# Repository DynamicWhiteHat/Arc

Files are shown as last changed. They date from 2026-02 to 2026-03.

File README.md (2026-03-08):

# Arc
A Wireless 75% Backlit Keyboard

> [!NOTE]
> Firmware available [here](https://github.com/DynamicWhiteHat/ArcFirmware)

## Features:
- HolyIOT 18010 MCU
- RGB backlight and underglow
- Nice!View e-paper display
- Wireless ZMK firmware

## Image Gallery:
<table align="center">
  <tr>
    <td align="center">
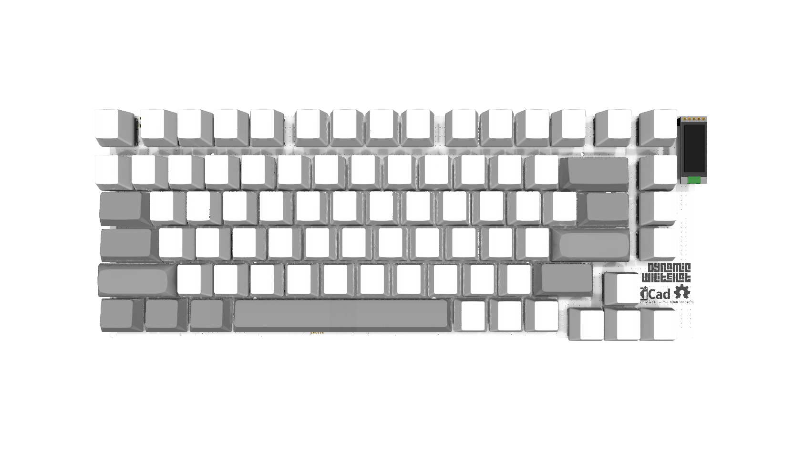
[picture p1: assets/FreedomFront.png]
      
    </td>
    <td align="center">
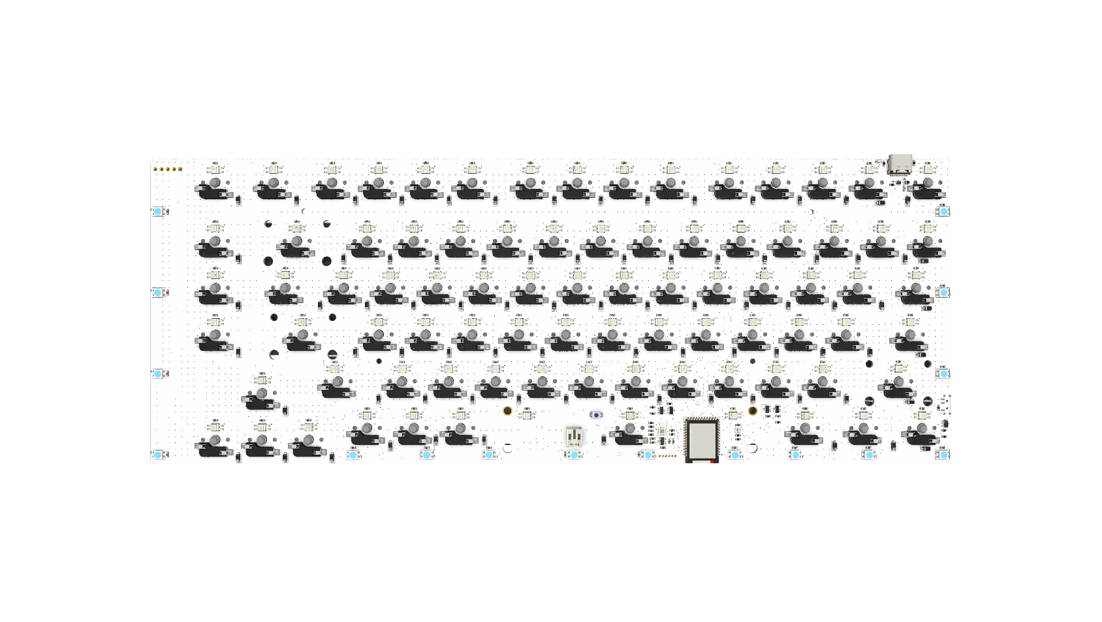
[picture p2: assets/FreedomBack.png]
      
    </td>
  </tr>
  <tr>
    <td align="center" colspan="2">
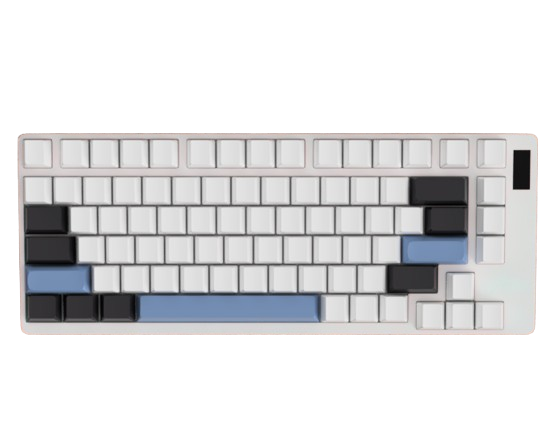
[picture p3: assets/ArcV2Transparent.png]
      
    </td>
  </tr>
</table>

## Why I Designed This Project:

After designing Corneucopia, I decided that I wanted to create a regular keyboard. I have attempted to make many in the past, but
I never got around to finishing them. Now that I had experience making a wireless split, I decided to make a wireless regular. This was also a test of making a PCB with just the MCU. Previously, I have made PCBs with the ESP32 SoM, but this was my first chip PCB that didn't use the ESP32.

## Schematics And PCBS:
<table align="center">
  <tr>
    <td align="center" colspan="2">
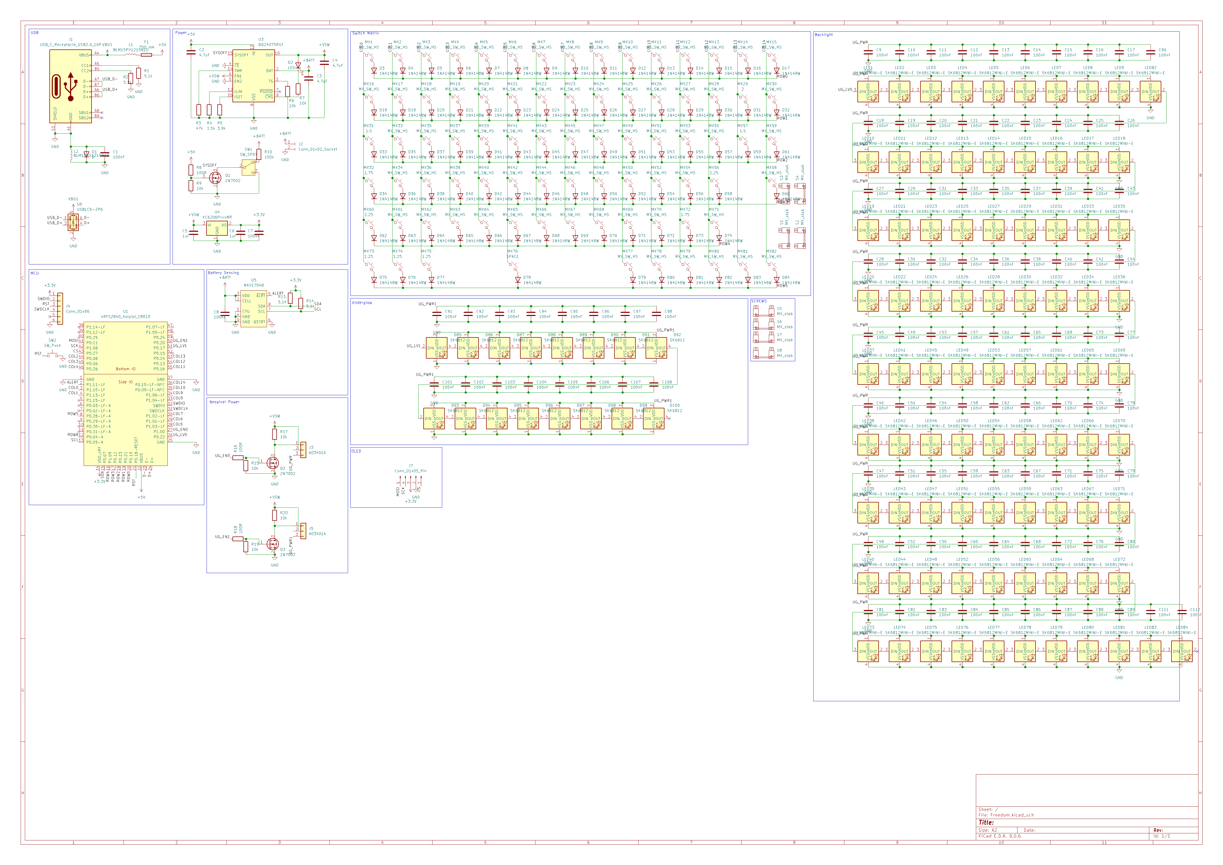
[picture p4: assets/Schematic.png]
      
    </td>
  </tr>
  <tr>
     <td align="center">
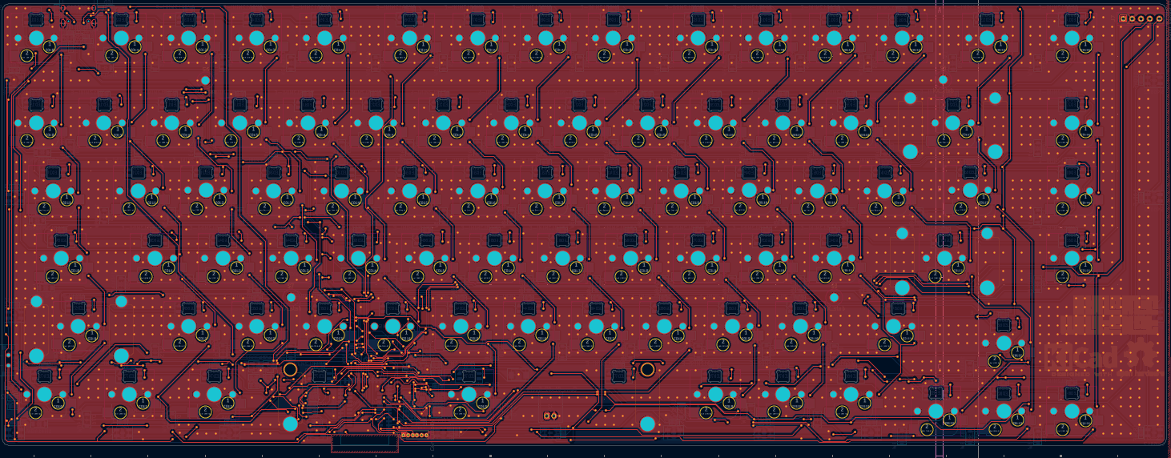
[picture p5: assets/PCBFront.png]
      
    </td>
    <td align="center">
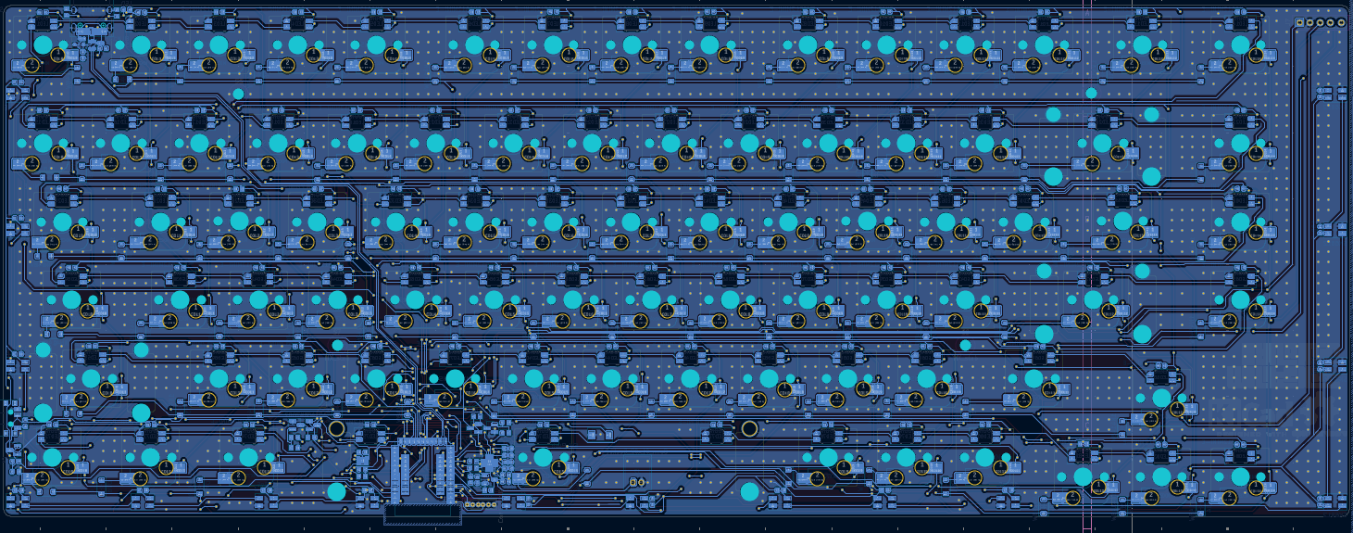
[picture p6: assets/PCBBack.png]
      
    </td>
  </tr>
</table>

## Usage:
The project features a design that keeps all screws hidden on the inside of the case, keeping a seamless look on the outside. This design has already been applied in [Corneucopia](https://github.com/DynamicWhiteHat/Corneucopia/). The PCB is screwed into the bottom case using 4 M2 screws. The top case is held in place by the hot-swappable switches. Once the PCB is assembled and the case is build, load the AdaFruit nrf52840 bootloader onto it, available [here](https://github.com/adafruit/Adafruit_nRF52_Bootloader). Follow [this guide](https://github.com/joric/nrfmicro/wiki/Bootloader) for more help. After adding the bootloader, enter dfu mode using the reset button and upload the .uf2 file from the firmware folder on this repository. The keyboard is now ready.

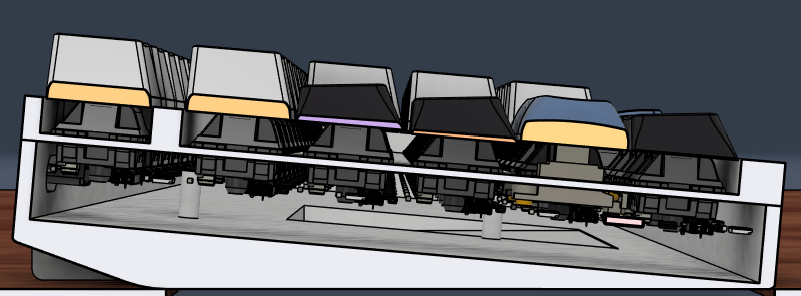
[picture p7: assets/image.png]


## Details:
Powered by a HolyIOT 18010, running ZMK firmware, this board supports a wireless Bluetooth connection. It uses the SK6812 mini-e for per-key RGB, and regular the sk6812 mini for underglow. A laser-cut stencil will be used to help with PCB assembly.

## BOM:
| Part | Quantity | Price | Link | | | | |
|---|---|---|---|---|---|---|---|
| PCB + Stencil | 1 Order | $40.56 | JLCPCB Quote | | | | |
| PCB Parts | 1 Order | $32.22 | See LCSC BOM | | | | |
| Switches | 2 Packs of 50 | $19.82 | https://www.aliexpress.us/item/3256806837508228.html | | | | |
| Hotswaps | 1 Pack Of 100 | $9.45 | https://www.aliexpress.us/item/2251832764937566.html | | | | |
| Stabilizers | 1 Pack | $17.99 | https://www.amazon.com/DUROCK-Stabilizers-Translucent-Keyboard-Mechanical/dp/B0B2RR8YB3/ | | | | |
| HolyIOT 18010 MCU | 1 | $12.84 | https://www.aliexpress.us/item/3256804605353119.html | | | | |
| Keycaps | 1 | $23.92 | https://www.aliexpress.com/i/3256807057714410.html | | | | |
| Lipo Battery | 1 | $10.49 | https://www.amazon.com/Qimoo-Battery-Rechargeable-Connector-Electronic/dp/B0CNLNKSKK/ | | | | |
| | | $167.29 | | | | | |
| LCSC | | | | | | | |
| Description | Quantity Needed | Mrf# | Minimum Order Qty. | Unit Price(USD) | Ext.Price(USD) | LCSC# | Product Link |
| 1.5k | 1 | 0603WAF1501T5E | 100 | 0.0012 | 0.12 | C22843 | https://www.lcsc.com/product-detail/C22843.html |
| 100R | 3 | 0603WAF1000T5E | 100 | 0.0012 | 0.12 | C22775 | https://www.lcsc.com/product-detail/C22775.html |
| 100k | 1 | 0603WAF1003T5E | 100 | 0.0011 | 0.11 | C25803 | https://www.lcsc.com/product-detail/C25803.html |
| 100nF | 103 | CC0603KRX7R9BB104  | 200 | 0.0021 | 0.42 | C14663 | https://www.lcsc.com/product-detail/C14663.html |
| 10k | 7 | 0603WAF1002T5E | 100 | 0.0012 | 0.12 | C25804 | https://www.lcsc.com/product-detail/C25804.html |
| 1N4148W | 82 | 1N4148W | 100 | 0.011 | 1.1 | C81598 | https://www.lcsc.com/product-detail/C81598.html |
| 1uF | 2 | CL10A105KB8NNNC | 50 | 0.0056 | 0.28 | C15849 | https://www.lcsc.com/product-detail/C15849.html |
| 2N7002 | 3 | 2N7002 | 50 | 0.0137 | 0.69 | C8545 | https://www.lcsc.com/product-detail/C8545.html |
| 3.9k | 1 | 0603WAF3901T5E | 100 | 0.0014 | 0.14 | C23018 | https://www.lcsc.com/product-detail/C23018.html |
| 4.7uF | 3 | CL10A475KO8NNNC | 10 | 0.0103 | 0.1 | C19666 | https://www.lcsc.com/product-detail/C19666.html |
| 47k | 1 | 0603WAF4702T5E | 100 | 0.0012 | 0.12 | C25819 | https://www.lcsc.com/product-detail/C25819.html |
| 5.1K | 1 | 0603WAF5101T5E | 100 | 0.0012 | 0.12 | C23186 | https://www.lcsc.com/product-detail/C23186.html |
| 5.1k | 3 | 0603WAF5101T5E | 100 | 0.0012 | 0.12 | C23186 | https://www.lcsc.com/product-detail/C23186.html |
| 750 mA | 1 | BSMD0603-075-6V | 10 | 0.0656 | 0.66 | C914092  | https://www.lcsc.com/product-detail/C914092.html  |
| A03401A | 2 | AO3401A | 10 | 0.0583 | 0.58 | C15127 | https://www.lcsc.com/product-detail/C15127.html |
| BLM15PX121SN1D | 2 | BLM15PX121SN1D | 100 | 0.0059 | 0.59 | C88970 | https://www.lcsc.com/product-detail/C88970.html |
| BQ24075RGT | 1 | BQ24075RGTT | 1 | 1.4633 | 1.46 | C2865459 | https://www.lcsc.com/product-detail/C2865459.html |
| Conn_01x02_Socket | 1 | S2B-PH-K-S(LF)(SN) | 20 | 0.0372 | 0.74 | C173752  | https://www.lcsc.com/product-detail/C173752.html  |
| D | 1 | BSD3C051V | 10 | 0.069 | 0.69 | C151996  | https://www.lcsc.com/product-detail/C151996.html  |
| LED | 1 | KT-0603W | 50 | 0.0118 | 0.59 | C2290 | https://www.lcsc.com/product-detail/C2290.html |
| MAX17048 | 1 | MAX17048G+T10 | 1 | 2.6708 | 2.67 | C2682616 | https://www.lcsc.com/product-detail/C2682616.html |
| SK6812 | 16 | SK6812SMINI | 20 | 0.0618 | 1.24 | C7423118 | https://www.lcsc.com/product-detail/C7423118.html |
| SK6812MINI-E | 84 | SK6812MINI-E | 85 | 0.0742 | 6.31 | C5149201 | https://www.lcsc.com/product-detail/C5149201.html |
| SW_Push | 1 | TS-1088-AR02016 | 10 | 0.0455 | 0.46 | C720477  | https://www.lcsc.com/product-detail/C720477.html  |
| SW_SPDT | 1 | SSSS811101 | 5 | 0.1439 | 0.72 | C109335  | https://www.lcsc.com/product-detail/C109335.html  |
| USBLC6-2P6 | 1 | USBLC6-2P6-MS | 5 | 0.1024 | 0.51 | C3647099 | https://www.lcsc.com/product-detail/C3647099.html |
| USB_C_Receptacle_USB2.0_16P | 1 | TYPE-C-31-M-12 | 5 | 0.1681 | 0.84 | C165948  | https://www.lcsc.com/product-detail/C165948.html  |
| XC6206PxxxMR | 1 | XC6206P332MR-G | 5 | 0.11 | 0.55 | C5446 | https://www.lcsc.com/product-detail/C5446.html |
| | | | | Subtotal: | $22.35 | | |
| | | | | Shipping: | $9.87 | | |
| | | | | Total: | $32.22 | | |

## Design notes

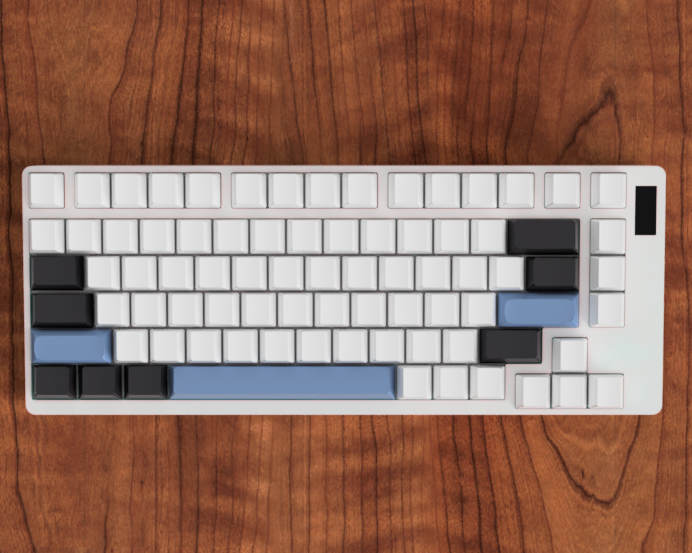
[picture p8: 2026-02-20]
assets/ArcV2.png

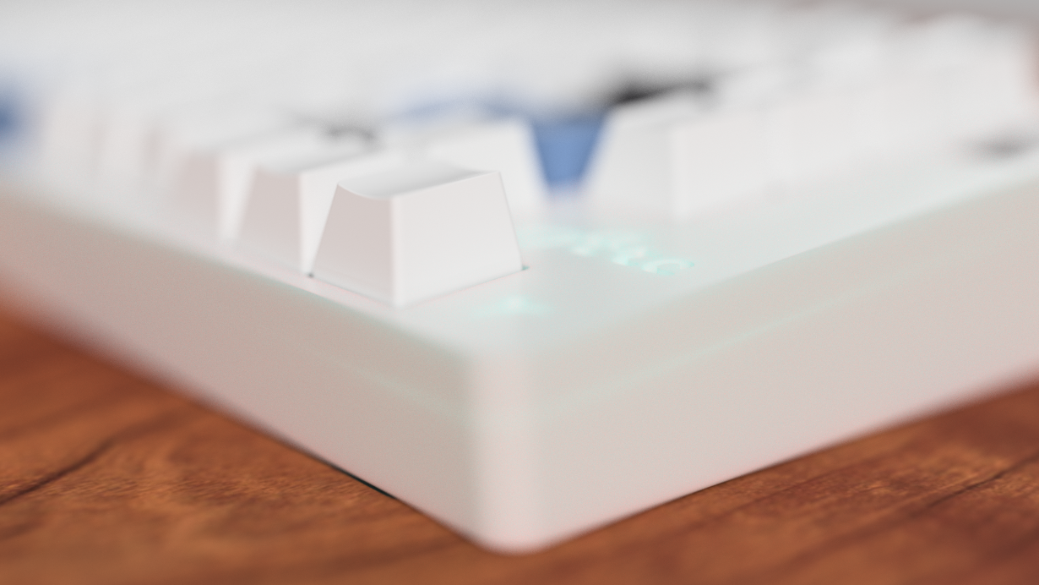
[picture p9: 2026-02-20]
assets/ArcV2Blur.png

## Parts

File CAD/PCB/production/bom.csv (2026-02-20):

Designator | Footprint | Quantity | Value | LCSC Part #
C1, C10, C101, C102, C103, C104, C105, C106, C107, C108, C11, C111, C112, C12, C13, C14, C15, C16, C17, C18, C19, C20, C21, C22, C23, C24, C25, C26, C27, C28, C29, C30, C31, C32, C33, C34, C35, C36, C37, C38, C39, C40, C41, C42, C43, C44, C45, C46, C47, C48, C49, C50, C51, C52, C53, C54, C55, C56, C57, C58, C59, C60, C61, C62, C63, C64, C65, C66, C67, C68, C69, C7, C70, C71, C72, C73, C74, C75, C76, C77, C78, C79, C8, C80, C81, C82, C83, C84, C85, C86, C87, C88, C89, C9, C90, C91, C92, C93, C94, C95, C96, C97, C98 | 0603 | 103 | 100nF
C2, C3, C4 | 0603 | 3 | 4.7uF
C5, C6 | 0603 | 2 | 1uF
D1 | D_SOD-323 | 1 | D
D10, D11, D12, D13, D14, D15, D16, D17, D18, D19, D20, D21, D22, D23, D24, D25, D26, D27, D28, D29, D3, D30, D31, D32, D33, D34, D35, D36, D37, D38, D39, D4, D40, D41, D42, D43, D44, D45, D46, D47, D48, D49, D5, D50, D51, D52, D53, D54, D55, D56, D57, D58, D59, D6, D60, D61, D62, D63, D64, D65, D66, D67, D68, D69, D7, D70, D71, D72, D73, D74, D75, D76, D77, D78, D79, D8, D80, D81, D82, D83, D84, D9 | D_SOD-123 | 82 | 1N4148W
D100, D85, D86, D87, D88, D89, D90, D91, D92, D93, D94, D95, D96, D97, D98, D99 | LED_SK6812MINI_PLCC4_3.5x3.5mm_P1.75mm | 16 | SK6812
D2 | 0603 | 1 | LED
F1 | 0603 | 1 | 750 mA
J1 | USB_C_Receptacle_HRO_TYPE-C-31-M-12 | 1 | USB_C_Receptacle_USB2.0_16P
J2 | JST_PH_S2B-PH-K_1x02_P2.00mm_Horizontal | 1 | Conn_01x02_Socket
J3, J5 | SOT-23 | 2 | A03401A
J4 | PinHeader_1x06_P1.27mm_Vertical | 1 | Conn_01x06
J7 | PinHeader_1x05_P2.54mm_Vertical | 1 | Conn_01x05_Pin
L1, L2 | 0402 | 2 | BLM15PX121SN1D
LED1, LED10, LED11, LED12, LED13, LED14, LED15, LED16, LED17, LED18, LED19, LED2, LED20, LED21, LED22, LED23, LED24, LED25, LED26, LED27, LED28, LED29, LED3, LED30, LED31, LED32, LED33, LED34, LED35, LED36, LED37, LED38, LED39, LED4, LED40, LED41, LED42, LED43, LED44, LED45, LED46, LED47, LED48, LED49, LED5, LED50, LED51, LED52, LED53, LED54, LED55, LED56, LED57, LED58, LED59, LED6, LED60, LED61, LED62, LED63, LED64, LED65, LED66, LED67, LED68, LED69, LED7, LED70, LED71, LED72, LED73, LED74, LED75, LED76, LED77, LED78, LED79, LED8, LED80, LED81, LED82, LED83, LED84, LED9 | LED_MX_6028R | 84 | SK6812MINI-E
MX1, MX10, MX11, MX12, MX13, MX14, MX15, MX16, MX17, MX18, MX19, MX2, MX20, MX21, MX22, MX23, MX24, MX25, MX26, MX27, MX28, MX3, MX30, MX33, MX34, MX35, MX36, MX37, MX38, MX39, MX4, MX40, MX41, MX42, MX43, MX44, MX45, MX46, MX47, MX48, MX49, MX5, MX50, MX51, MX52, MX53, MX54, MX55, MX58, MX59, MX6, MX61, MX62, MX63, MX64, MX65, MX66, MX67, MX68, MX69, MX7, MX70, MX71, MX77, MX78, MX79, MX8, MX80, MX81, MX82, MX9 | SW_MX_HS_CPG151101S11_1u | 71 | MX_SW_HS
MX29 | SW_MX_HS_CPG151101S11_2u | 1 | 2
MX31, MX57 | SW_MX_HS_CPG151101S11_1.5u | 2 | 1.5
MX32, MX72 | SW_MX_HS_CPG151101S11_1.75u | 2 | 1.75
MX56, MX60 | SW_MX_HS_CPG151101S11_2.25u | 2 | 2.25
MX73, MX74, MX75 | SW_MX_HS_CPG151101S11_1.25u | 3 | 1.25
MX76 | SW_MX_HS_CPG151101S11_6u | 1 | SPACE
Q1, Q2, Q3 | SOT-23 | 3 | 2N7002
R1, R13, R14, R2 | 0603 | 4 | 5.1k
R10 | 0603 | 1 | 100k
R15, R17, R19, R20, R6, R7, R9 | 0603 | 7 | 10k
R16, R18, R8 | 0603 | 3 | 100R
R3 | 0603 | 1 | 47k
R4 | 0603 | 1 | 1.5k
R5 | 0603 | 1 | 3.9k
S1 | STAB_MX_P_6.25u | 1 | MX_stab
S2, S4 | STAB_MX_2.25u | 2 | MX_stab
S3 | STAB_MX_2u | 1 | MX_stab
S5, S6, S7, S8 | MountingHole_2.2mm_M2 | 4 | MX_stab
SW1 | SW_SSSS811101 | 1 | SW_SPDT
SW2 | SW_TS-1088-AR02016 | 1 | SW_Push
U1 | nRF52840_holyiot_18010 | 1 | nRF52840_holyiot_18010
U3 | VQFN-16-1EP_3x3mm_P0.5mm_EP1.6x1.6mm | 1 | BQ24075RGT
U4 | SOT-23-3 | 1 | XC6206PxxxMR
U5 | DFN-8-1EP_2x2mm_P0.5mm_EP0.8x1.6mm | 1 | MAX17048
U6 | SOT-666 | 1 | USBLC6-2P6

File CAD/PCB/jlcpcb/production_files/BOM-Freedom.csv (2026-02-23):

Comment | Designator | Footprint | LCSC | Quantity
1.5k | R4 | R_0603_1608Metric | C22843 | 1
100R | R16,R18,R8 | R_0603_1608Metric | C22775 | 3
100k | R10 | R_0603_1608Metric | C25803 | 1
100nF | C1,C10,C101,C102,C103,C104,C105,C106,C107,C108,C11,C111,C112,C12,C13,C14,C15,C16,C17,C18,C19,C20,C21,C22,C23,C24,C25,C26,C27,C28,C29,C30,C31,C32,C33,C34,C35,C36,C37,C38,C39,C40,C41,C42,C43,C44,C45,C46,C47,C48,C49,C50,C51,C52,C53,C54,C55,C56,C57,C58,C59,C60,C61,C62,C63,C64,C65,C66,C67,C68,C69,C7,C70,C71,C72,C73,C74,C75,C76,C77,C78,C79,C8,C80,C81,C82,C83,C84,C85,C86,C87,C88,C89,C9,C90,C91,C92,C93,C94,C95,C96,C97,C98 | C_0603_1608Metric | C14663 | 103
10k | R15,R17,R19,R20,R6,R7,R9 | R_0603_1608Metric | C25804 | 7
1N4148W | D10,D11,D12,D13,D14,D15,D16,D17,D18,D19,D20,D21,D22,D23,D24,D25,D26,D27,D28,D29,D3,D30,D31,D32,D33,D34,D35,D36,D37,D38,D39,D4,D40,D41,D42,D43,D44,D45,D46,D47,D48,D49,D5,D50,D51,D52,D53,D54,D55,D56,D57,D58,D59,D6,D60,D61,D62,D63,D64,D65,D66,D67,D68,D69,D7,D70,D71,D72,D73,D74,D75,D76,D77,D78,D79,D8,D80,D81,D82,D83,D84,D9 | D_SOD-123 | C81598 | 82
1uF | C5,C6 | C_0603_1608Metric | C15849 | 2
2N7002 | Q1,Q2,Q3 | SOT-23 | C8545 | 3
3.9k | R5 | R_0603_1608Metric | C23018 | 1
4.7uF | C2,C3,C4 | C_0603_1608Metric | C19666 | 3
47k | R3 | R_0603_1608Metric | C25819 | 1
5.1K | R13 | R_0603_1608Metric | C23186 | 1
5.1k | R1,R14,R2 | R_0603_1608Metric | C23186 | 3
750 mA | F1 | Fuse_0603_1608Metric | C914092 | 1
A03401A | J3,J5 | SOT-23 | C9900019683 | 2
BLM15PX121SN1D | L1,L2 | C_0402_1005Metric | C88970 | 2
BQ24075RGT | U3 | VQFN-16-1EP_3x3mm_P0.5mm_EP1.6x1.6mm | C2865459 | 1
Conn_01x02_Socket | J2 | JST_PH_S2B-PH-K_1x02_P2.00mm_Horizontal | C173752 | 1
D | D1 | D_SOD-323 | C151996 | 1
LED | D2 | LED_0603_1608Metric | C2290 | 1
MAX17048 | U5 | DFN-8-1EP_2x2mm_P0.5mm_EP0.8x1.6mm | C2682616 | 1
SK6812 | D100,D85,D86,D87,D88,D89,D90,D91,D92,D93,D94,D95,D96,D97,D98,D99 | LED_SK6812MINI_PLCC4_3.5x3.5mm_P1.75mm | C7423118 | 16
SK6812MINI-E | LED1,LED10,LED11,LED12,LED13,LED14,LED15,LED16,LED17,LED18,LED19,LED2,LED20,LED21,LED22,LED23,LED24,LED25,LED26,LED27,LED28,LED29,LED3,LED30,LED31,LED32,LED33,LED34,LED35,LED36,LED37,LED38,LED39,LED4,LED40,LED41,LED42,LED43,LED44,LED45,LED46,LED47,LED48,LED49,LED5,LED50,LED51,LED52,LED53,LED54,LED55,LED56,LED57,LED58,LED59,LED6,LED60,LED61,LED62,LED63,LED64,LED65,LED66,LED67,LED68,LED69,LED7,LED70,LED71,LED72,LED73,LED74,LED75,LED76,LED77,LED78,LED79,LED8,LED80,LED81,LED82,LED83,LED84,LED9 | LED_MX_6028R | C5149201 | 84
SW_Push | SW2 | SW_TS-1088-AR02016 | C720477 | 1
SW_SPDT | SW1 | SW_SSSS811101 | C109335 | 1
USBLC6-2P6 | U6 | SOT-666 | C3647099 | 1
USB_C_Receptacle_USB2.0_16P | J1 | USB_C_Receptacle_HRO_TYPE-C-31-M-12 | C165948 | 1
XC6206PxxxMR | U4 | SOT-23-3 | C5446 | 1
MX_stab | S6 | MountingHole_2.2mm_M2 |  | 1
Conn_01x06 | J4 | PinHeader_1x06_P1.27mm_Vertical |  | 1
MX_stab | S7 | MountingHole_2.2mm_M2 |  | 1
MX_stab | S1 | STAB_MX_P_6.25u |  | 1
Conn_01x05_Pin | J7 | PinSocket_1x05_P2.54mm_Vertical |  | 1
MX_stab | S8 | MountingHole_2.2mm_M2 |  | 1
MX_stab | S4 | STAB_MX_2.25u |  | 1
MX_stab | S3 | STAB_MX_2u |  | 1
MX_stab | S5 | MountingHole_2.2mm_M2 |  | 1
MX_stab | S2 | STAB_MX_2.25u |  | 1
MX_SW_HS | MX37 | SW_MX_HS_CPG151101S11_1u |  | 1
1.75 | MX32 | SW_MX_HS_CPG151101S11_1.75u |  | 1
1.75 | MX72 | SW_MX_HS_CPG151101S11_1.75u |  | 1
MX_SW_HS | MX80 | SW_MX_HS_CPG151101S11_1u |  | 1
MX_SW_HS | MX33 | SW_MX_HS_CPG151101S11_1u |  | 1
MX_SW_HS | MX79 | SW_MX_HS_CPG151101S11_1u |  | 1
nRF52840_holyiot_18010 | U1 | nRF52840_holyiot_18010 |  | 1
1.25 | MX75 | SW_MX_HS_CPG151101S11_1.25u |  | 1
SPACE | MX76 | SW_MX_HS_CPG151101S11_6u |  | 1
2 | MX29 | SW_MX_HS_CPG151101S11_2u |  | 1
MX_SW_HS | MX2 | SW_MX_HS_CPG151101S11_1u |  | 1
1.5 | MX31 | SW_MX_HS_CPG151101S11_1.5u |  | 1
MX_SW_HS | MX64 | SW_MX_HS_CPG151101S11_1u |  | 1
MX_SW_HS | MX42 | SW_MX_HS_CPG151101S11_1u |  | 1
MX_SW_HS | MX66 | SW_MX_HS_CPG151101S11_1u |  | 1
1.5 | MX57 | SW_MX_HS_CPG151101S11_1.5u |  | 1
MX_SW_HS | MX22 | SW_MX_HS_CPG151101S11_1u |  | 1
MX_SW_HS | MX17 | SW_MX_HS_CPG151101S11_1u |  | 1
MX_SW_HS | MX53 | SW_MX_HS_CPG151101S11_1u |  | 1
MX_SW_HS | MX52 | SW_MX_HS_CPG151101S11_1u |  | 1
MX_SW_HS | MX41 | SW_MX_HS_CPG151101S11_1u |  | 1
MX_SW_HS | MX21 | SW_MX_HS_CPG151101S11_1u |  | 1
MX_SW_HS | MX54 | SW_MX_HS_CPG151101S11_1u |  | 1
MX_SW_HS | MX51 | SW_MX_HS_CPG151101S11_1u |  | 1
MX_SW_HS | MX62 | SW_MX_HS_CPG151101S11_1u |  | 1
MX_SW_HS | MX59 | SW_MX_HS_CPG151101S11_1u |  | 1
MX_SW_HS | MX55 | SW_MX_HS_CPG151101S11_1u |  | 1
MX_SW_HS | MX46 | SW_MX_HS_CPG151101S11_1u |  | 1
MX_SW_HS | MX45 | SW_MX_HS_CPG151101S11_1u |  | 1
MX_SW_HS | MX43 | SW_MX_HS_CPG151101S11_1u |  | 1
MX_SW_HS | MX49 | SW_MX_HS_CPG151101S11_1u |  | 1
MX_SW_HS | MX6 | SW_MX_HS_CPG151101S11_1u |  | 1
MX_SW_HS | MX20 | SW_MX_HS_CPG151101S11_1u |  | 1
MX_SW_HS | MX13 | SW_MX_HS_CPG151101S11_1u |  | 1
MX_SW_HS | MX69 | SW_MX_HS_CPG151101S11_1u |  | 1
MX_SW_HS | MX39 | SW_MX_HS_CPG151101S11_1u |  | 1
MX_SW_HS | MX27 | SW_MX_HS_CPG151101S11_1u |  | 1
1.25 | MX73 | SW_MX_HS_CPG151101S11_1.25u |  | 1
MX_SW_HS | MX28 | SW_MX_HS_CPG151101S11_1u |  | 1
MX_SW_HS | MX5 | SW_MX_HS_CPG151101S11_1u |  | 1
MX_SW_HS | MX8 | SW_MX_HS_CPG151101S11_1u |  | 1
MX_SW_HS | MX4 | SW_MX_HS_CPG151101S11_1u |  | 1
MX_SW_HS | MX25 | SW_MX_HS_CPG151101S11_1u |  | 1
MX_SW_HS | MX16 | SW_MX_HS_CPG151101S11_1u |  | 1
MX_SW_HS | MX63 | SW_MX_HS_CPG151101S11_1u |  | 1
MX_SW_HS | MX19 | SW_MX_HS_CPG151101S11_1u |  | 1
MX_SW_HS | MX9 | SW_MX_HS_CPG151101S11_1u |  | 1
MX_SW_HS | MX81 | SW_MX_HS_CPG151101S11_1u |  | 1
MX_SW_HS | MX40 | SW_MX_HS_CPG151101S11_1u |  | 1
1.25 | MX74 | SW_MX_HS_CPG151101S11_1.25u |  | 1
MX_SW_HS | MX67 | SW_MX_HS_CPG151101S11_1u |  | 1
MX_SW_HS | MX68 | SW_MX_HS_CPG151101S11_1u |  | 1
MX_SW_HS | MX30 | SW_MX_HS_CPG151101S11_1u |  | 1
MX_SW_HS | MX58 | SW_MX_HS_CPG151101S11_1u |  | 1
MX_SW_HS | MX65 | SW_MX_HS_CPG151101S11_1u |  | 1
MX_SW_HS | MX24 | SW_MX_HS_CPG151101S11_1u |  | 1
MX_SW_HS | MX35 | SW_MX_HS_CPG151101S11_1u |  | 1
MX_SW_HS | MX34 | SW_MX_HS_CPG151101S11_1u |  | 1
MX_SW_HS | MX1 | SW_MX_HS_CPG151101S11_1u |  | 1
MX_SW_HS | MX14 | SW_MX_HS_CPG151101S11_1u |  | 1
MX_SW_HS | MX47 | SW_MX_HS_CPG151101S11_1u |  | 1
MX_SW_HS | MX77 | SW_MX_HS_CPG151101S11_1u |  | 1
MX_SW_HS | MX23 | SW_MX_HS_CPG151101S11_1u |  | 1
MX_SW_HS | MX48 | SW_MX_HS_CPG151101S11_1u |  | 1
MX_SW_HS | MX38 | SW_MX_HS_CPG151101S11_1u |  | 1
MX_SW_HS | MX82 | SW_MX_HS_CPG151101S11_1u |  | 1
MX_SW_HS | MX12 | SW_MX_HS_CPG151101S11_1u |  | 1
MX_SW_HS | MX70 | SW_MX_HS_CPG151101S11_1u |  | 1
MX_SW_HS | MX11 | SW_MX_HS_CPG151101S11_1u |  | 1
MX_SW_HS | MX78 | SW_MX_HS_CPG151101S11_1u |  | 1
MX_SW_HS | MX3 | SW_MX_HS_CPG151101S11_1u |  | 1
MX_SW_HS | MX26 | SW_MX_HS_CPG151101S11_1u |  | 1
MX_SW_HS | MX7 | SW_MX_HS_CPG151101S11_1u |  | 1
2.25 | MX56 | SW_MX_HS_CPG151101S11_2.25u |  | 1
MX_SW_HS | MX71 | SW_MX_HS_CPG151101S11_1u |  | 1
MX_SW_HS | MX18 | SW_MX_HS_CPG151101S11_1u |  | 1
MX_SW_HS | MX61 | SW_MX_HS_CPG151101S11_1u |  | 1
MX_SW_HS | MX50 | SW_MX_HS_CPG151101S11_1u |  | 1
2.25 | MX60 | SW_MX_HS_CPG151101S11_2.25u |  | 1
MX_SW_HS | MX36 | SW_MX_HS_CPG151101S11_1u |  | 1
MX_SW_HS | MX15 | SW_MX_HS_CPG151101S11_1u |  | 1
MX_SW_HS | MX10 | SW_MX_HS_CPG151101S11_1u |  | 1
MX_SW_HS | MX44 | SW_MX_HS_CPG151101S11_1u |  | 1

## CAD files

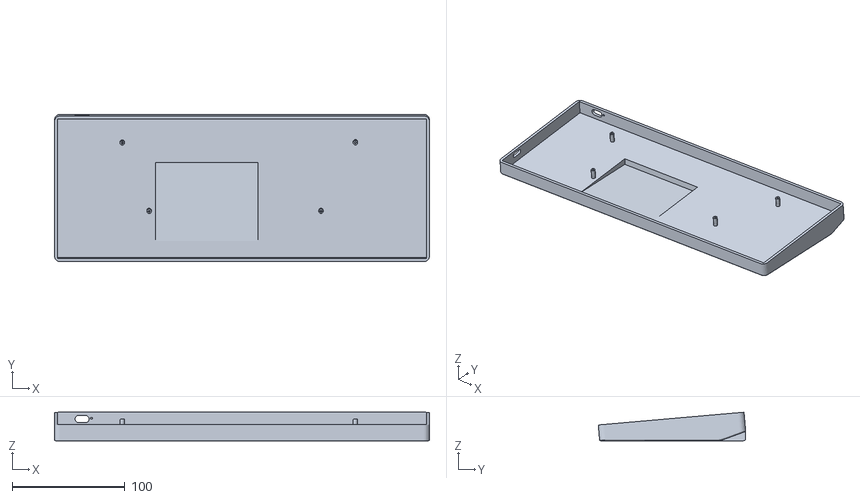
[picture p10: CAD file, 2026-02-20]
CAD/Case/STL/Bottom.stl
332.6 x 130.8 x 25.4

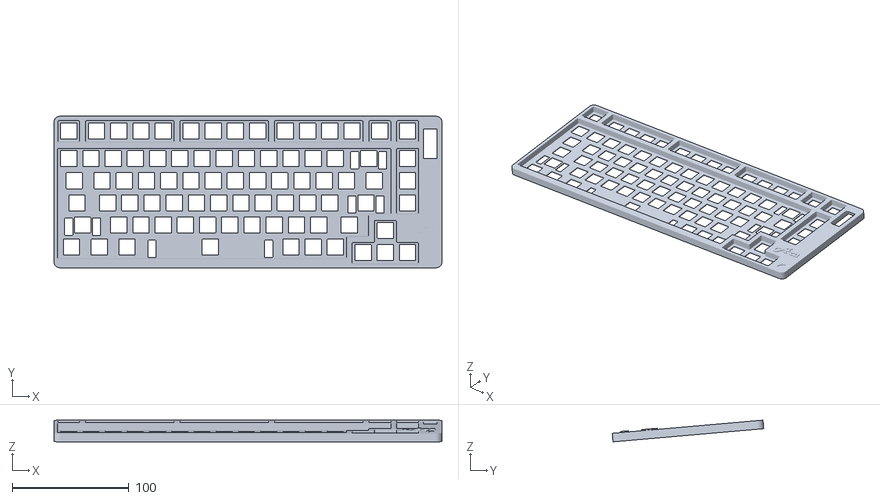
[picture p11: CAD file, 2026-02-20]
CAD/Case/STL/Top.stl
332.6 x 130.0 x 18.6

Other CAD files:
CAD/Arc.f3z

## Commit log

2026-02-20 Updated Repo
    [BOM-Freedom.csv, BOM.csv, Bottom.stl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]
2026-02-20 Added main file
    [Arc.f3z]
2026-02-20 Update image dimensions in README.md for schematic and PCB visuals
2026-02-23 Added new PCB files
    [BOM-Freedom.csv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]
2026-02-23 Added new BOM
    [BOM.csv]
2026-02-23 Change 'Mounting' section to 'Usage' with details
    Updated section header from 'Mounting' to 'Usage' and expanded usage instructions.
2026-02-24 Revise technical details section in README
    Updated section headers and added details about PCB assembly.
2026-03-08 Revise BOM with updated parts and pricing
    Updated BOM with new quantities and prices for components.
